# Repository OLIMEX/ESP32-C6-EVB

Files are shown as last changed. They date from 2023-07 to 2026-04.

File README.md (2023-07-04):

# ESP32-C6-EVB
ESP32-C6-EVB is evaluation board with WiFi6, Bluetooth 5LE and Zigbee Matter support

Product page: https://www.olimex.com/Products/IoT/ESP32-C6/ESP32-C6-EVB/open-source-hardware
## License
* Hardware is released under CERN OHL v1.2 license
* Software is released under GPL3 License
* Documentation is released under CC BY-SA 3.0

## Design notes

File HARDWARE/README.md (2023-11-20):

# ESP32-C6-EVB

Design files for Olimex ESP32-C6-EVB. Board is made with KiCAD. This is an open-source hardware project, released under CERN OHL v1.2 license.

STL files for a 3d printed case can be found in directory "3D printed case". All STL files were created with Fusion 360.

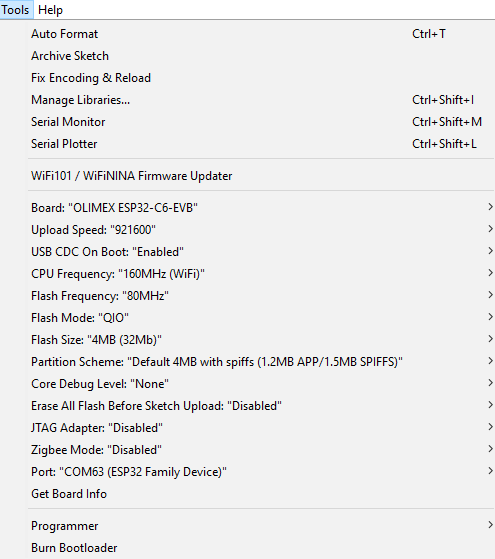
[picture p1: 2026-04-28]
SOFTWARE/ARDUINO/esp32-c6-serial-control/arduino-settings.jpg

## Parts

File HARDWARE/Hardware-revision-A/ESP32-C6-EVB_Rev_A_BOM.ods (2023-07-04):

Qty | Designation | Package | Designator
1 | 0.03R/1%/R1206 | R_1206_5MIL_DWS | R4
1 | 4.7R/R0402 | R_0402_5MIL_DWS | R12
1 | 100R/R0402 | R_0402_5MIL_DWS | R32
8 | 2.2k/R0402 | R_0402_5MIL_DWS | R3,R11,R15,R27,R28,R29,R30,R31
4 | 3.9k/R1206 | R_1206_5MIL_DWS | R5,R6,R7,R8
2 | 5.1k/R0603 | R_0603_5MIL_DWS | R1,R2
1 | 5.23k/1%/R0402 | R_0402_5MIL_DWS | R13
4 | 10k/R0402 | R_0402_5MIL_DWS | R14,R16,R25,R26
1 | 30.1k/1%/R0402 | R_0402_5MIL_DWS | R17
4 | 47k/R0402 | R_0402_5MIL_DWS | R21,R22,R23,R24
1 | 49.9k/1%/R0402 | R_0402_5MIL_DWS | R20
1 | 220k/R0402 | R_0402_5MIL_DWS | R19
1 | 12pF/50V/5%/COG/C0402 | C_0402_5MIL_DWS | C5
2 | 100nF/100V/10%/X7R/C0603 | C_0603_5MIL_DWS | C2,C4
1 | 100nF/10V/10%/X7R/C0402 | C_0402_5MIL_DWS | C10
1 | 1uF/10V/10%/X5R/C0603 | C_0603_5MIL_DWS | C11
4 | 22uF/6.3V/20%/X5R/C0603 | C_0603_5MIL_DWS | C3,C7,C8,C9
1 | 100uF/63V/20%/10x13MM/Low_ESR/RM5 | CPOL-RM5mm_10.0x16.0mm_PTH | C1
1 | 470uF/10V/20%/Low_ESR/RM2.5/6x11mm | CPOL-RM2.5mm_6.3x11mm_PTH | C6
1 | 2.2uH/NRS3015T2R2MNGH/1.5A/ DCR=72mR/20%/3.00x3.00x1.50mm | CD32 | L2
1 | 33uH/2A/DCR=0.1R/20%/ DBS135(PD3316MT330) | DBS135 | L1
1 | SMAJ58A/SMA | SMA-KA | D1
8 | 1N4148W(SOD-123) | SOD-123_1C-2A_KA | D2,D3,D4,D5,D8,D9,D10,D11
1 | SS310/SMA | SMA-KA | D6
1 | 1N5822/SS34/SMA | SMA-KA | D7
5 | LED/RED/0603 | LED_0603_KA | LED1,LED2,LED3,LED4,PWR_LED1
5 | LED/GREEN/0603 | LED_0603_KA | LED5,LED6,LED7,LED8,USER_LED1
4 | LMUN2235LT1G(SOT-23) | SOT23 | T1,T2,T3,T4
1 | WPM2015-3/TR | SOT23 | FET1
4 | PC817CS_CYPC817(C-TP2) | H11A817C_SMD(PC817X3NIP06)_FP | OPT1,OPT2,OPT3,OPT4
1 | ESP32-C6-WROOM-1-N4 | ESP32-C6-WROOM-1-xx-UNI_MODULE | U3
1 | TX4138(ESOIC-8) | ESOIC-8 | U1
1 | SY8089AAAC(SOT23-5) | SOT-23-5 | U2
4 | RAS-0515 | Relay_RAS-05-15 | REL1,REL2,REL3,REL4
1 | USB-C-16P-F(A40-00119-A52-12) | USB2.0_TYPE-C(A40-00119-A52-12) | USB-OTG1
1 | P-B-V-10-LF | GBH-254-SMT-10 | UEXT1
4 | DG306-5.0-3P | TB3-DG306-5.0_3P | CON1,CON2,CON3,CON4
4 | DG306-5.0-2P | TB2-DG306-5.0_2P | IN1,IN2,IN3,IN4
1 | NA(DG306-5.0-2P) | TB2-DG306-5.0_2P | PWR2
1 | PWRJ-2mm(YDJ-1134) | PWRJ-2mm(YDJ-1136) | PWR1
1 | SM10B-SRSS-TB | SM10B-SRSS-TB | UEXT2
2 | YTS-A016-X | YTS-A016-X | BUT1,RST1
1 | Opened | SJ_1_SMALLER | 3.3V_E1
1 | NA(WU06S) | WU06S | ESP-PROG1
1 | NA(HN1x10) | HN1x10 | EXT1
3 | NA/R0402 | R_0402_5MIL_DWS | R9,R10,R18
2 | NA(2.2k/R0402) | R_0402_5MIL_DWS | R33,R34

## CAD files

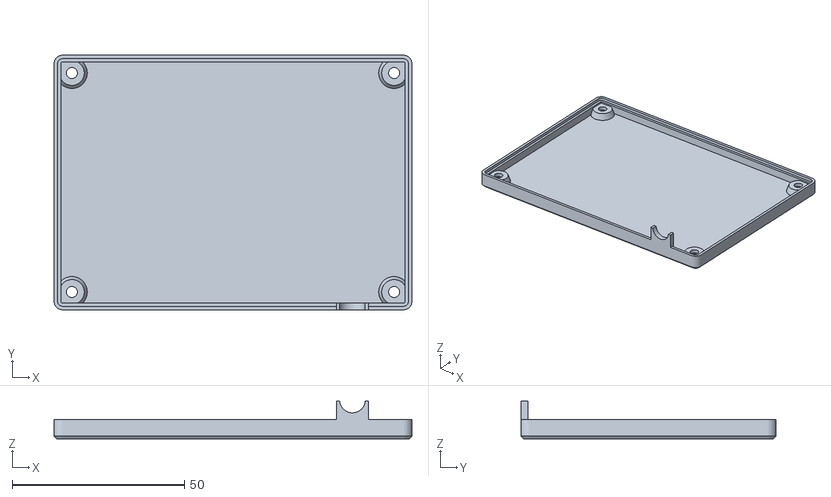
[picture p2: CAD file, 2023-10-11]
HARDWARE/3D printed case/esp_c6_evb_bottom.stl
104.0 x 74.0 x 11.0

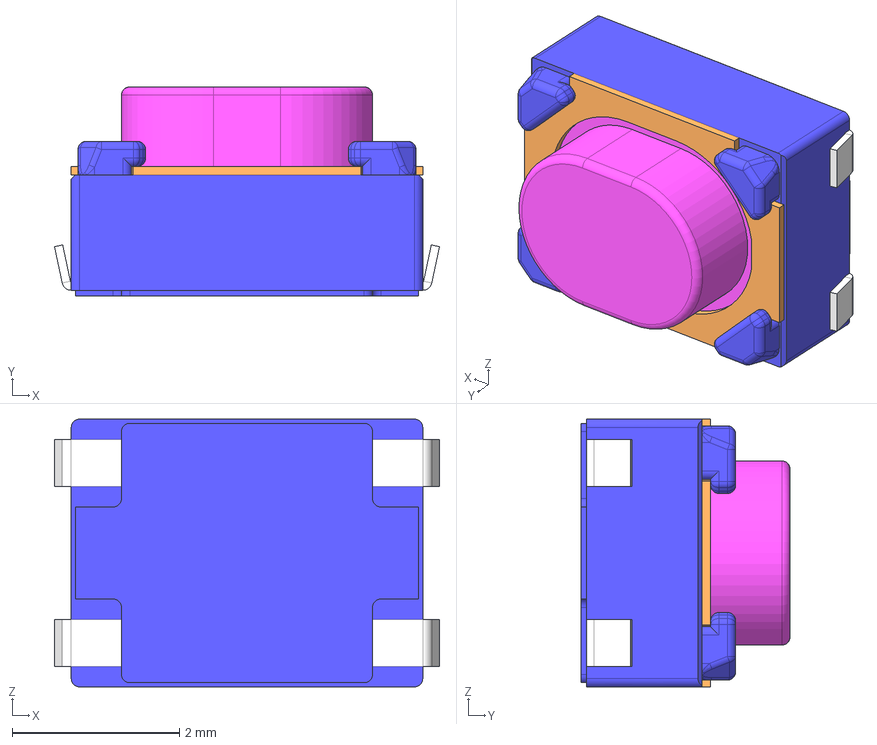
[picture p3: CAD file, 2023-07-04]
HARDWARE/Hardware-revision-A/3d/YTS-A016-X(SKRPABE010).stp
4.60 x 2.50 x 3.20 mm

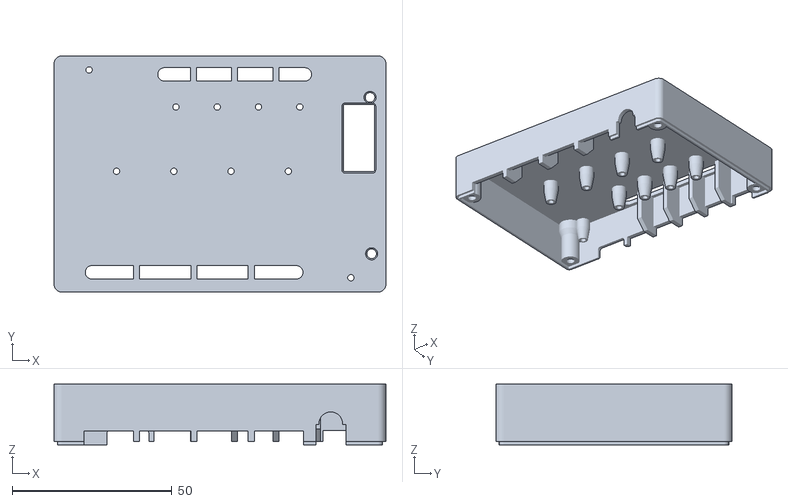
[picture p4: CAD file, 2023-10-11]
HARDWARE/3D printed case/esp_c6_evb_top.stl
104.0 x 74.0 x 19.0

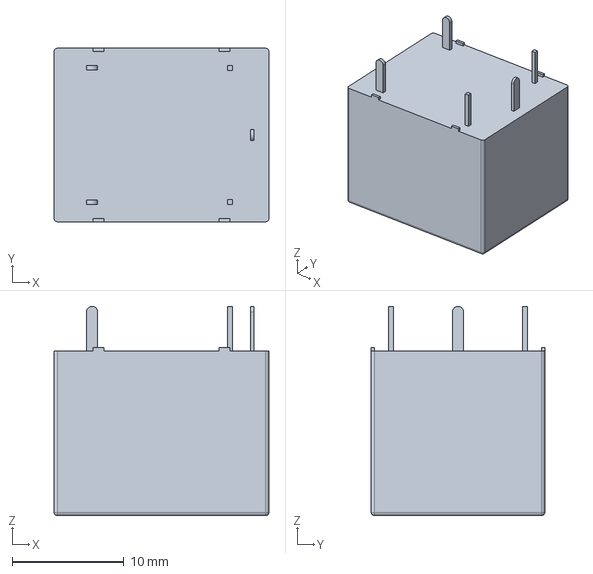
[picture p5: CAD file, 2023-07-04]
HARDWARE/Hardware-revision-A/3d/TEConnectivity -ORWH-SH-124D1F000.stp
19.2 x 15.5 x 18.7 mm

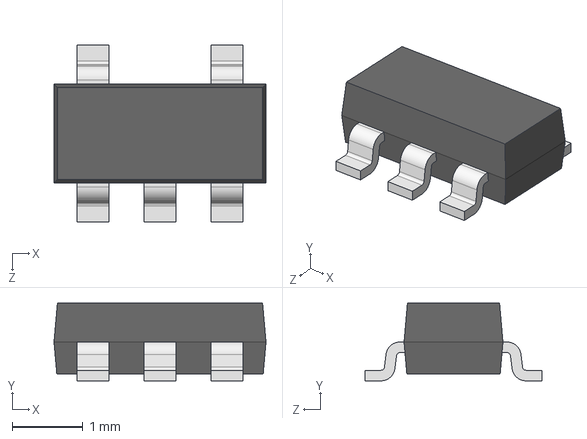
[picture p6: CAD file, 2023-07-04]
HARDWARE/Hardware-revision-A/3d/SOT-23-5.step
3.00 x 1.10 x 2.50 mm

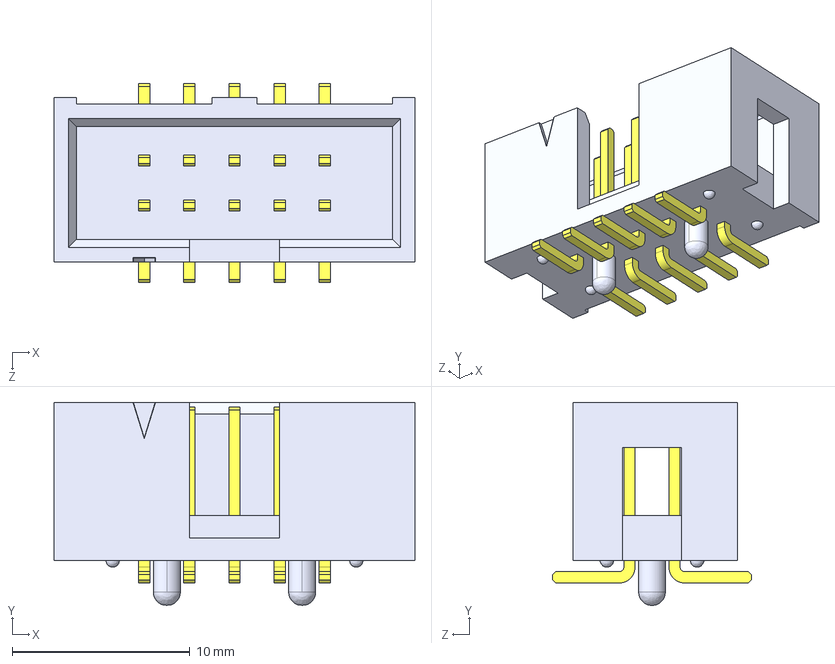
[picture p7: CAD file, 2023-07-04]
HARDWARE/Hardware-revision-A/3d/UEXT-SMD.STEP
20.3 x 11.4 x 11.2 mm
User Library-HTST-105-01-F-DV-A__HTST-105-01-DV-A_header
User Library-HTST-105-01-F-DV-A__HTST-First_Position_Indicator
User Library-HTST-105-01-F-DV-A__T-1S6-05-01-DV_

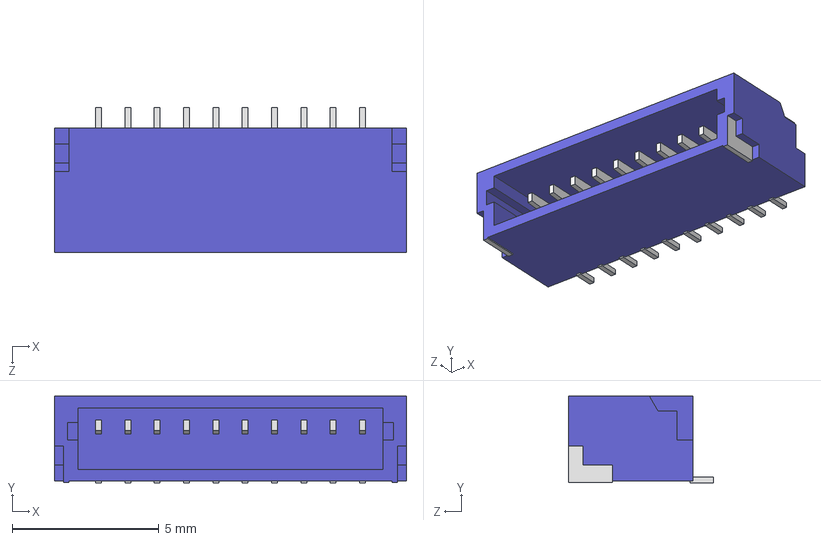
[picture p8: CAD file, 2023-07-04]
HARDWARE/Hardware-revision-A/3d/SM10B-SRSS-TB.STEP
12.0 x 2.96 x 4.95 mm

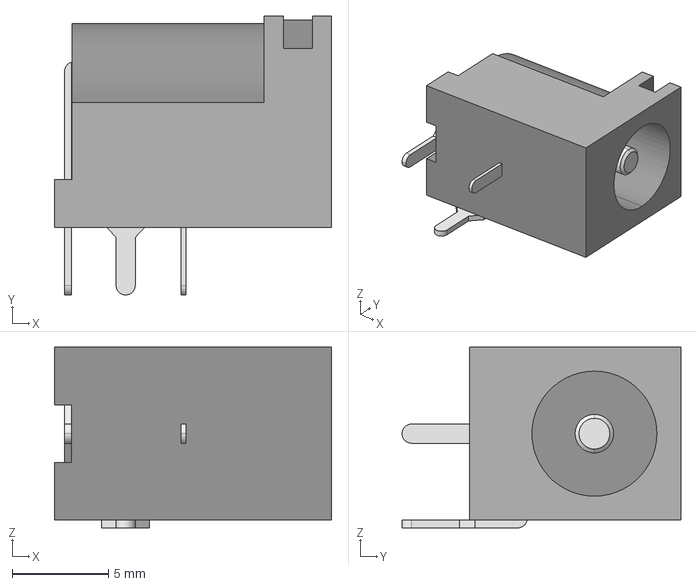
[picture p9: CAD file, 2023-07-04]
HARDWARE/Hardware-revision-A/3d/pj-102ah.stp
14.4 x 14.5 x 9.40 mm

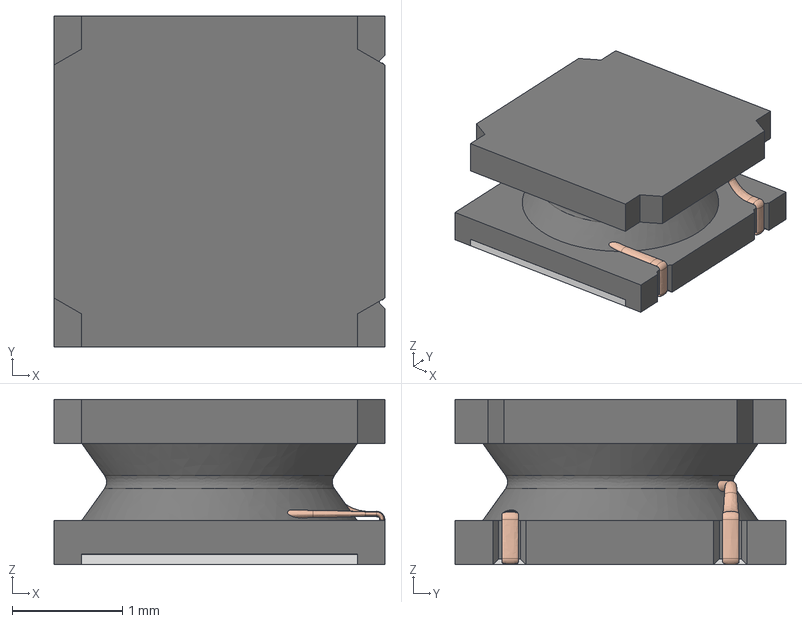
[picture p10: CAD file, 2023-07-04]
HARDWARE/Hardware-revision-A/3d/L-CD32_shielded.step
3.00 x 3.00 x 1.50 mm

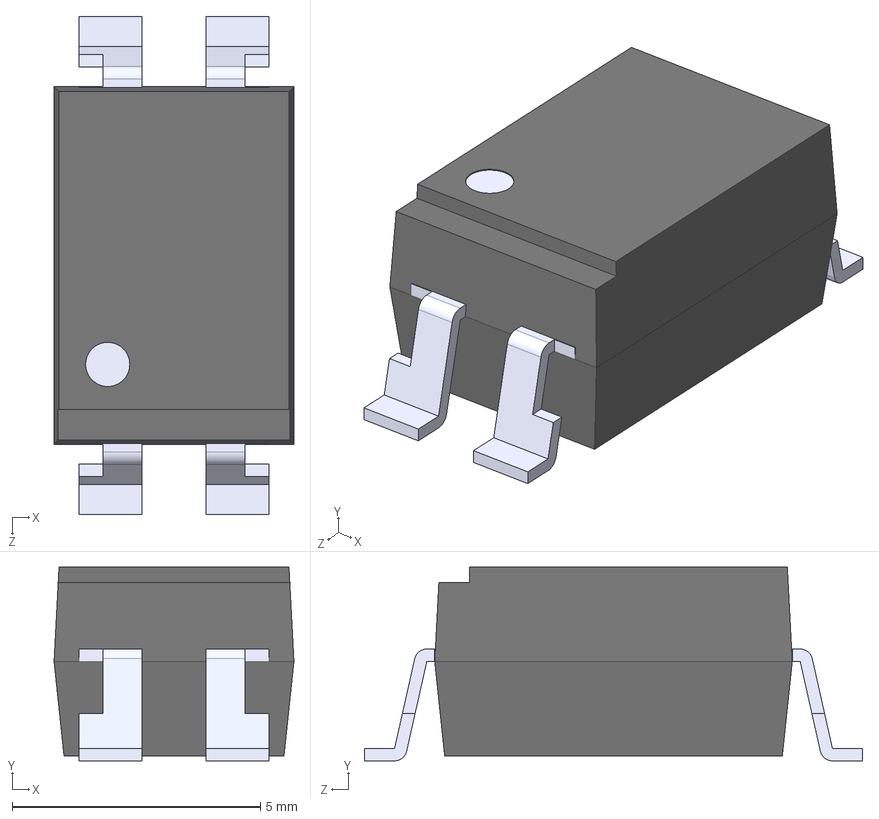
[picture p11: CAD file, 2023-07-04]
HARDWARE/Hardware-revision-A/3d/DIP4_opto_iso.step
4.83 x 3.90 x 10.0 mm

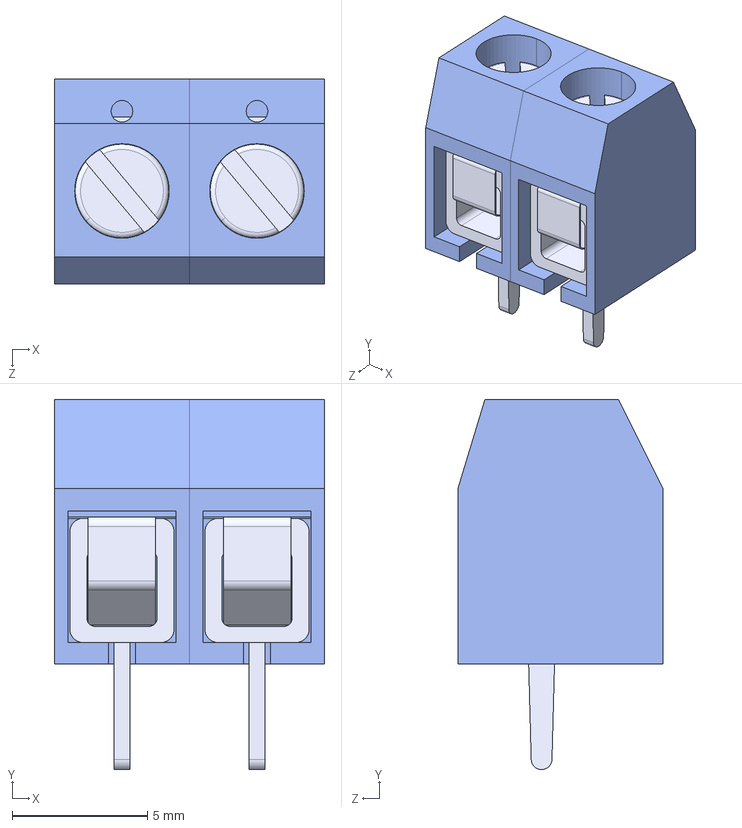
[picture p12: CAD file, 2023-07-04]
HARDWARE/Hardware-revision-A/3d/User Library-DG306-5_0-1.STEP
10.00 x 13.7 x 7.60 mm
Case___ _________ x 2
Leg___ _________ x 2
Spring___ _________ x 2
Cap___ _________ x 2

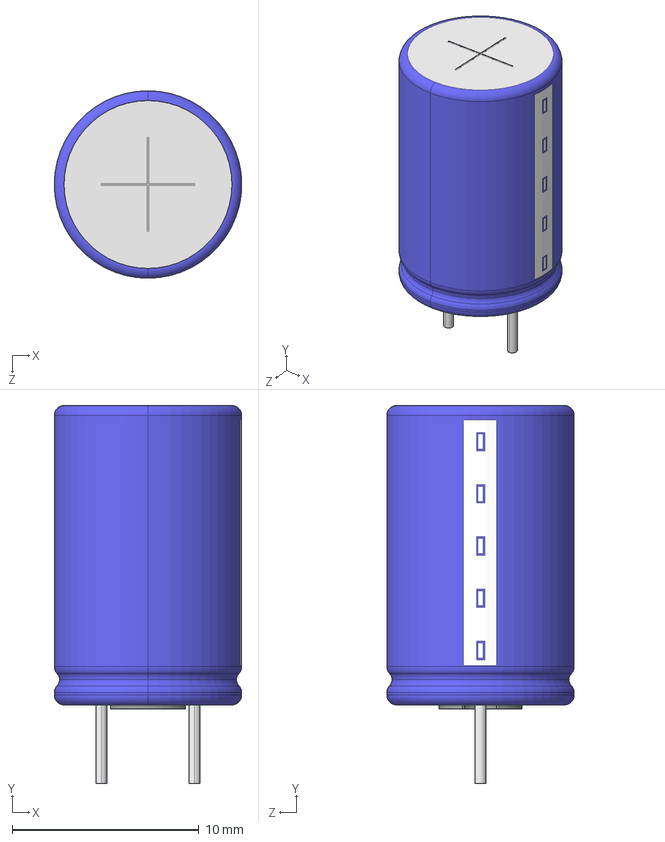
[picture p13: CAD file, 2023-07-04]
HARDWARE/Hardware-revision-A/3d/Cap_PTH_10x16x5_0mm.step
10.1 x 20.3 x 10.1 mm

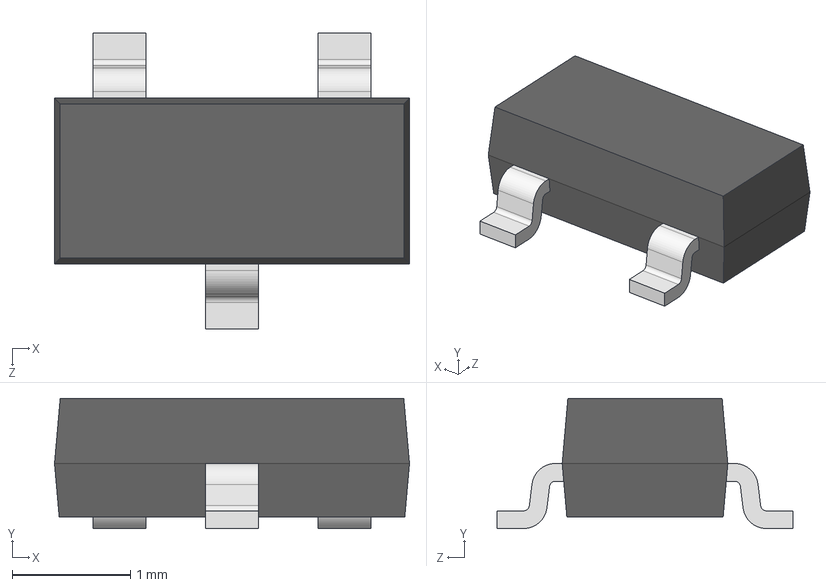
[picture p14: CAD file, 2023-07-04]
HARDWARE/Hardware-revision-A/3d/SOT-23.step
3.00 x 1.10 x 2.50 mm

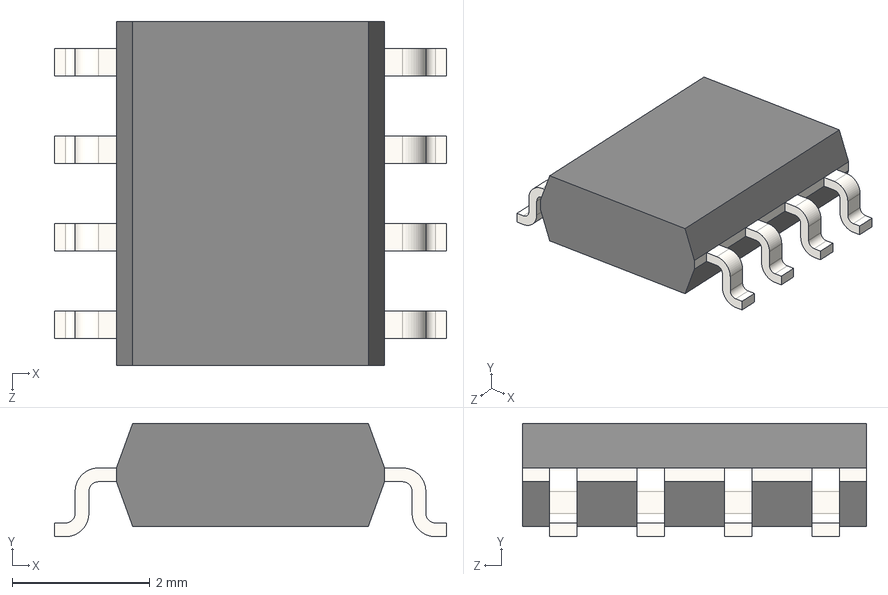
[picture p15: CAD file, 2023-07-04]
HARDWARE/Hardware-revision-A/3d/SL08.step
5.70 x 1.65 x 5.00 mm

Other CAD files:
HARDWARE/Hardware-revision-A/3d/Cap_PTH_6_3x11x2_5mm.step
HARDWARE/Hardware-revision-A/3d/klema-5mm-3pin.step
HARDWARE/Hardware-revision-A/3d/ESP32-WROOM-32D-56544.STEP
HARDWARE/Hardware-revision-A/3d/DO-214AC_SMA.step
HARDWARE/Hardware-revision-A/3d/L_AX97-103R3.step
HARDWARE/Hardware-revision-A/3d/SOD123.step

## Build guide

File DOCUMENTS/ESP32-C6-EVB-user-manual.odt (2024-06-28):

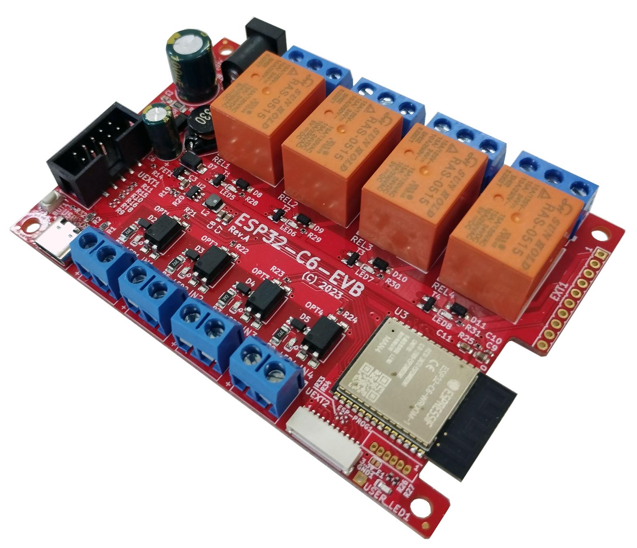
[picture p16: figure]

ESP32-C6-EVB

User Manual

Revision 2.0 June 2024 www.olimex.com

# INTRODUCTION

## What is ESP32-C6-EVB?

ESP32-C6-EVB (https://www.olimex.com/Products/IoT/ESP32-C6/ESP32-C6-EVB/open-source-hardware) is a WIFI-enabled and Bluetooth-enabled development board that also has free GPIOs, analog, and digital inputs and outputs on boxed connector and more.

ESP32-C6-EVB (https://www.olimex.com/Products/IoT/ESP32-C6/ESP32-C6-EVB/open-source-hardware) uses ESP32-C6, Espressif’s first Wi-Fi 6 (IEEE 802.11ax) module. It integrates 2.4 GHz Wi-Fi 6, Bluetooth 5 (LE), and the 802.15.4 low-rate wireless personal area network (LR-WPAN).

ESP32-C6-EVB (https://www.olimex.com/Products/IoT/ESP32-C6/ESP32-C6-EVB/open-source-hardware) is perfect for stand-alone usage but can also be attached to any existing hardware project to augment it with with 2.4GHz Wi-Fi 6 and Bluetooth LE 5.3 capabilities.

ESP32-C6-EVB (https://www.olimex.com/Products/IoT/ESP32-C6/ESP32-C6-EVB/open-source-hardware) requires only a USB cable for programming and powering; the board is equipped with USB type C connector, the type of cable used for charging most mobile phones.

ESP32-C6-EVB (https://www.olimex.com/Products/IoT/ESP32-C6/ESP32-C6-EVB/open-source-hardware) is an Open Source Hardware project, all CAD source files are available at our GitHub repositories (https://github.com/OLIMEX/ESP32-C6-EVB/tree/main/HARDWARE). Files are released under CERN Open Hardware License Version 2 – strongly reciprocal and allows users to learn, study, edit, modify, manufacture, and sell same, or derivative products based on these designs. The only requirements is to open source their work under the same license.

The software environment for code development is free. There are a number of different software environments that can be used for the board.

Espressif chips and modules are very popular, with excellent chip documentation. The community around ESP chips is huge. This greatly eases both hardware and software development.

ESP32-C6-EVB (https://www.olimex.com/Products/IoT/ESP32-C6/ESP32-C6-EVB/open-source-hardware) is RoHS, REACH, CE, and UKCA compliant.

## ESP32-C6-EVB board features

ESP32-C6-EVB is Open Source Hardware design with the following features:

- ESP32-C6-WROOM-1-N4 module with 32-bit RISC-V single-core microprocessor, up to 160 MHz, Flash: 4MB, ROM: 320 KB, HP SRAM: 512 KB, LP SRAM: 16 KB
- USB-C connector for powering, programming, and JTAG debugging
- Power jack for optional external power (8-50)V DC
- Four Relays: 10A/240VAC
- Four opto-isolated inputs for DC voltage up to 30VDC
- Two UEXT connectors (0.1" step one and JST one)
- Extension GPIO connector
- Reset button
- User button
- Wide range of power supply: 8-50VDC
- Programming connector suitable for ESP-PROG (https://www.olimex.com/Products/IoT/Programmer/ESP-PROG/open-source-hardware)
- Four mount holes
- Four rubber pads included

## Order codes and links for ESP32-C6-EVB and accessories:

ESP32-C6-EVB (https://www.olimex.com/Products/IoT/ESP32-C6/ESP32-C6-EVB/open-source-hardware) ESP32-C6 development and evaluation board with 4 relays, 4 opto-isolated inputs, and more.

CABLE-USB-A-C-1M (https://www.olimex.com/Products/Components/Cables/CABLE-USB-A-C-1M/) USB cable with USB type C and USB type A connectors, 1 meter

SY0612E (https://www.olimex.com/Products/Power/SY0612E/) 12V DC power adapter for external powering, compatible with the power jack (https://www.olimex.com/wiki/PWRJACK) of ESP32-C6-EVB; notice that it comes with European-style socket plug, if you are located in UK or USB consider PWR-EU-EK (https://www.olimex.com/Products/Power/PWR-EU-UK/) or PWR-EU-US (https://www.olimex.com/Products/Power/PWR-EU-US/) adapter

ESP-PROG (https://www.olimex.com/Products/IoT/Programmer/ESP-PROG/open-source-hardware) External USB-serial adapter that can be attached to ESP32-C6-EVB and used to program the ESP32-C6, or restore its firmware

CABLE-IDC10-15cm (https://www.olimex.com/Products/Components/Cables/CABLE-IDC10-15cm/) 10-pin female-female UEXT cable

JW-200x10-FM (https://www.olimex.com/Products/Breadboarding/JUMPER-WIRES/JW-200x10-FM/) 10 pieces female-male jumper wires for breadboarding

JW-200x10 (https://www.olimex.com/Products/Breadboarding/JUMPER-WIRES/JW-200x10/) 10 pieces male-male jumper wires for breadboarding

JW-200x10-FF (https://www.olimex.com/Products/Breadboarding/JUMPER-WIRES/JW-200x10-FF/) 10 pieces female-female jumper wires for breadboarding

UEXT modules (https://www.olimex.com/Products/Modules/) Different sensors, relays, LCDs, RTC, GSM, GPS etc accessories which can be connected to the UEXT connector

## ESP32-C6 reference documents:

- ESP32-C6-WROOM-1U-N4 (the module used in ESP32-C6-EVB) datasheet:

https://www.espressif.com/sites/default/files/documentation/esp32-c6-wroom-1_wroom-1u_datasheet_en.pdf

- ESP32-C6 series (the chip in ESP32-C6-WROOM-1U-N4 and, respectively, in ESP32-C6-EVB) datasheet:

https://www.espressif.com/sites/default/files/documentation/esp32-c6_datasheet_en.pdf

- Getting started with ESP32-C6 and ESP-IDF software environment:

https://docs.espressif.com/projects/esp-idf/en/latest/esp32c6/get-started/

- Getting started with ESP32-C6 and ESP32 package for Arduino IDE and PlatformIO software environments:

https://docs.espressif.com/projects/arduino-esp32/en/latest/getting_started.html

# HARDWARE

## ESP32-C6-EVB layout

4 x Relays with connectors and status LEDs (10A/240VAC max)

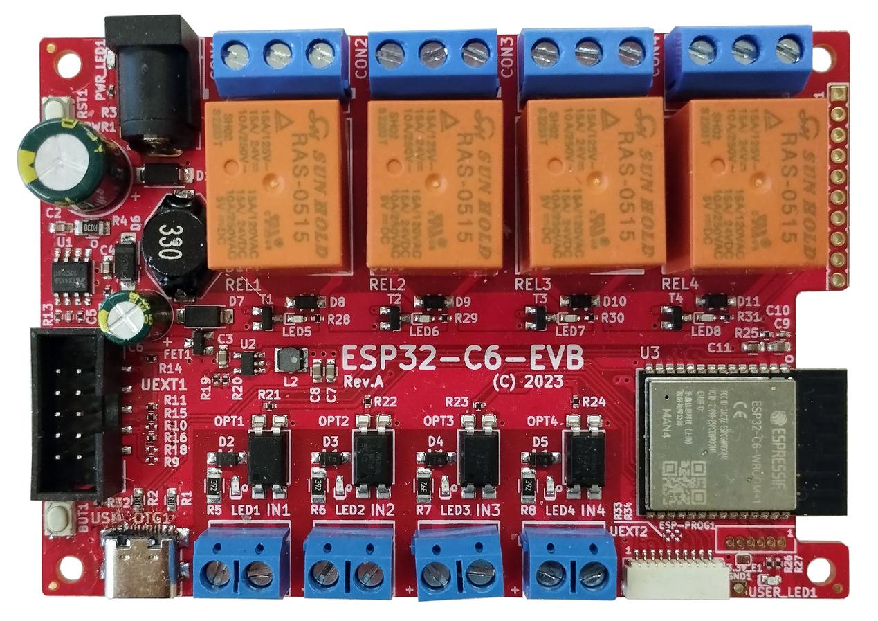
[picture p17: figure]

Power-good LED

Power jack input

(8-50)V DC

Reset button RST1

EXT1 header

4 x Opto-coupler inputs with connectors and status LEDs (30V DC max)

User LED

USB type C

for power and

programming

Boot/User button BUT1

UEXT1 connector 0.1” step

ESP-PROG1 header

UEXT2 connector (JST)

## ESP32-C6-EVB schematic

The latest ESP32-C6-EVB (https://www.olimex.com/Products/IoT/ESP32-C6/ESP32-C6-EVB/open-source-hardware) schematic is available on the next page.

You can also download PDF export from GitHu (https://github.com/OLIMEX/ESP32-C6-EVB/blob/main/HARDWARE/Hardware-revision-A/ESP32-C6-EVB_Rev_A.pdf)b here (https://github.com/OLIMEX/ESP32-C6-EVB/blob/main/HARDWARE/Hardware-revision-A/ESP32-C6-EVB_Rev_A.pdf)

All design sources are available also at GitHub (https://github.com/OLIMEX/ESP32-C6-EVB/tree/main/HARDWARE)here (https://github.com/OLIMEX/ESP32-C6-EVB/tree/main/HARDWARE)

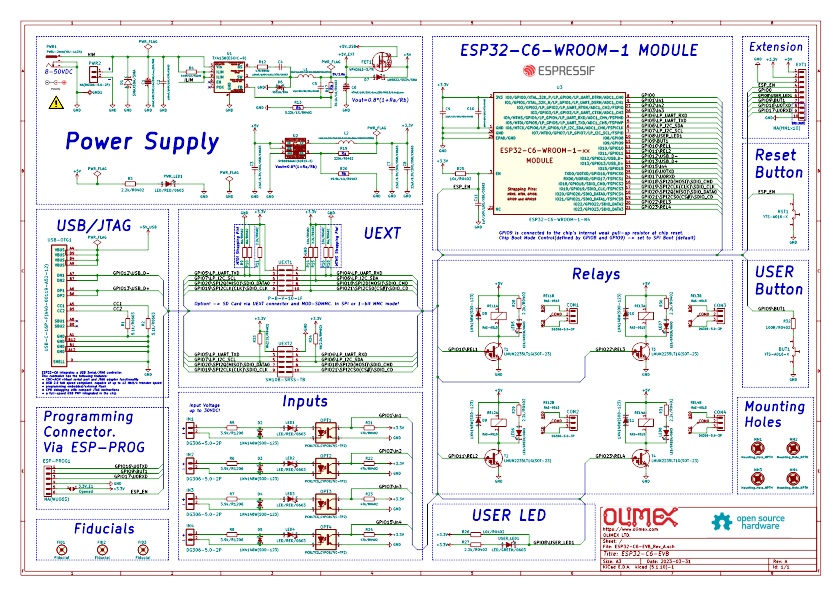
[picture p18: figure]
SVG Picture created as ESP32-C6-EVB_Rev_A.svg date 2023/08/03 15:58:47 Picture generated by Eeschema-SVG

## ESP32-C6-EVB power supply and consumption:

(https://www.olimex.com/Products/Retro-Computers/AgonLight2/open-source-hardware)

ESP32-C6-EVB can be powered by 3 sources:

- USB-C connector;
- Power jack connector;
- EXT1.pin1 (+5V) note that this wire is connected to the 5V of the USB so when you power ESP32-C6-EVB from EXT1.pin1 – you should not have USB cable attached at the same time!!!

The typical power consumption is under 1W. Current consumption of ESP32-C6-EVB is approximately 0.06A when powered by 12V DC (applied to the power jack).

## EXT1 connector (GPIO)

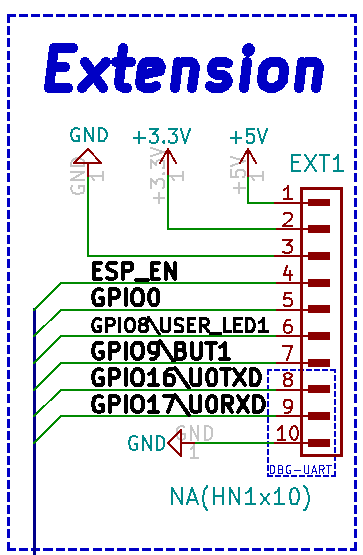
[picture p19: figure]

EXT1 pin #1 is +5V pin; it is usually used as output you can also power the board from this pins BUT ONLY IF the USB-C is not connected! It must be regulated 5V power supply, applying more than 5V will damage the board;

EXT1 pin #2 is +3.3V DC output, it is not recommended to be used as input since you can’t fully power the board with 3.3V DC (relays require 5V DC);

EXT1 pin #3, EXT1 pin #10 are GND pins, the board has common ground;

EXT1 pin #4 is ESP_EN also known as reset;

EXT1 pin #5 is GPIO0, which a free pin;

EXT1 pin #6 is GPIO8\USER_LED1 – wired to GPIO8, notice that the user LED is on the same wire

EXT1 pin #7 is GPIO9\BUT1 – wired to GPIO9, notice that the button is on the same wire

EXT1 pin #8 and EXT1 pin #9 are GPIO16\U0TXD and GPIO16\U0RXD they can be used for attaching external USB-serial converter (like ESP-PROG, USB-SERIAL-CABLE-M, or BB-CH340T) to debug the board; same pins are also routed to the ESP-PROG1 header.

All GPIOs operate at +3.3V levels. This means you should not connect signals with voltage higher than 3.3V to these ports as this will damage the board.

## UEXT connectors

UEXT connector stands for Universal EXTension connector and contains +3.3V output and GND power wires, and I2C, SPI, UART data signals. All signals are at 3.3V levels.

ESP32-C6-EVB has two UEXT connectors – UEXT1 and UEXT2, they have the same signals just different connector.

UEXT1 uses 0.1” 2.54mm step 2-row boxed plastic connector.

UEXT2 uses the smallest pUEXT which is 1.0mm single row JST connector.

Excerpts for UEXT1 and UEXT2 connectors can be seen below:

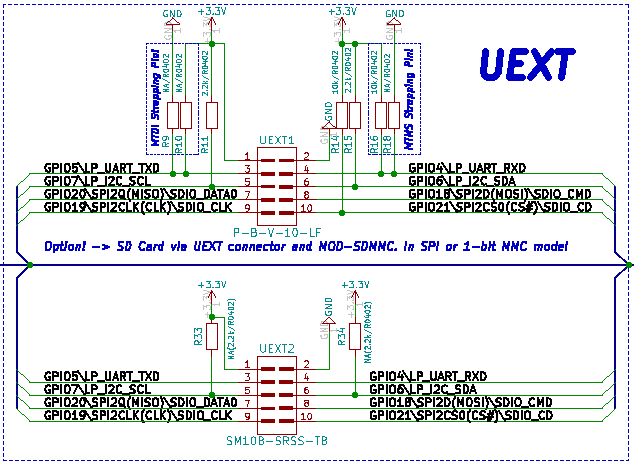
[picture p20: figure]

Olimex has developed number of extension MODULES (https://www.olimex.com/Products/Modules/) compatible with connector UEXT1. There are temperature, humidity, pressure, magnetic field, light sensors. Modules with LCDs, extra GPIOs, LED matrices, relays, Bluetooth, GSM, GPS, RFID, RTC, EKG, etc.

If you decide to use UEXT2 you might need adapter for the connector pUEXT. Expect adapter boards and wires for the JST UEXT2 connector.

## Relays

The board has 4 electro-mechanical relays for analog output, each relay has own status LED. Relay connectors have Normal open, Normal closed, and Common contacts.

Relay REL1 is connected to GPIO10

Relay REL2 to GPIO11

Relay REL3 goes to GPIO22

Relay REL4 to GPIO23

## Inputs

The board has 4 optocouplers for analog input and each input has own status LED. The inputs have + and – printed under the connector – make sure to first check the polarity or you might damage the board.

Opto OPT1 is connected to GPIO1

Opto OPT2 goes to GPIO2

Opto OPT3 is routed to GPIO3

Opto OPT4 is connected to GPIO15

## User LED and button BUT1

The board has user LED and a button that can be used as boot button but also can be used as user button after initial boot sequence.

LED is connected to GPIO8

Button BUT1 is connected to GPIO9

## ESP32-PROG header

Used to program the board with external serial-USB programmer like (like ESP-PROG (https://www.olimex.com/Products/IoT/Programmer/ESP-PROG/open-source-hardware))

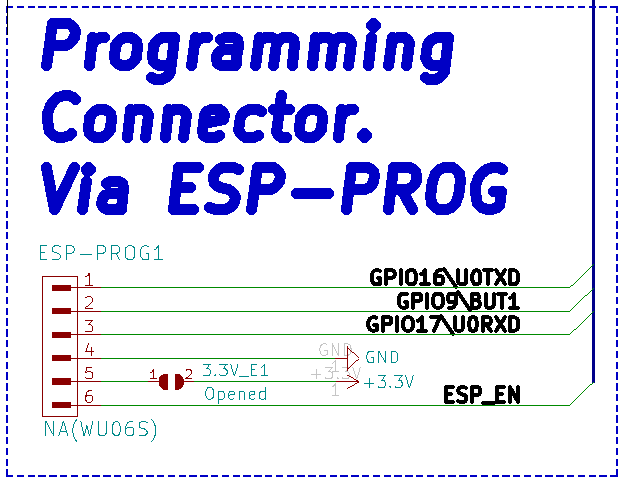
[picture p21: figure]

## Jumper 3.3V_E1

ESP32-C6-EVB has a single SMT jumpers on-board. SMT jumpers are pads that can be separated (open) or soldered together (closed) to alter the hardware connections of the board and alter the behavior. The SMT jumpers require basic soldering tools and experience, to separate them you need to cut between the pads and to close them you need to solder the pads together. SMT jumpers can also be used for measuring and testing purposes.

Typically you don’t need to change the positions of the jumpers to use the board. It is not recommended to alter the SMT jumpers unless you know exactly how they alter the board.

3.3V_E1 – enable 3.3V input on pin #5 of ESP-PROG1 connector – risky to leave 3.3V on the ESP-PROG1 connector, this might lead to short-circuit, if the board is already powered and you attach ESP-PROG (https://www.olimex.com/Products/IoT/Programmer/ESP-PROG/open-source-hardware).

Default state: Open (no 3.3V on pin #5 of ESP-PROG1 connector).

# SOFTWARE

## First time start up or how to program the board

The first time setup is pretty straight-forward and the general approach is the following:

1) Install compatible software on your computer (your computer should meet the requirements of the software); the official and recommended software is ESP-IDF (https://docs.espressif.com/projects/esp-idf/en/latest/esp32c6/get-started/); but you can also use ESP32 package for Arduino IDE (https://docs.espressif.com/projects/arduino-esp32/en/latest/getting_started.html)

2) Attach the ESP32-C6-EVB to the computer via USB cable, the cable needs to have USB type C connector at one end and usually USB type A at the other to fit your computer; a lot of devices use similar cables so you might already have such cable at home;

3) Force the board in upload/bootloader mode manually:

- Press and hold button BUT1

- Press and release button RST1

- Release button BUT1;

4) Download code. If you are unhappy with the default demos. Maybe check our ESP-IDF demo software for the relays, user LED, button – Olimex ESP32-C6-EVB demo code (https://github.com/OLIMEX/ESP32-C6-EVB/tree/main/SOFTWARE/ESP-IDF) and there is some extra info about it here (https://github.com/OLIMEX/ESP32-C6-EVB/blob/main/SOFTWARE/ESP-IDF/ESP32-C6-EVB_Blink/ESP32-C6-EVB_README.txt)in this text file (https://github.com/OLIMEX/ESP32-C6-EVB/blob/main/SOFTWARE/ESP-IDF/ESP32-C6-EVB_Blink/ESP32-C6-EVB_README.txt);

5) After download is complete you might need to reboot the board to have the user code execute. Future downloads would require entering upload/bootloader mode again (refer to 3).

## Olimex tested firmware and examples

These can be found in the repository here:

https://github.com/OLIMEX/ESP32-C6-EVB

# DOCUMENT REVISION

Revision 2.0 June 2024

- minor improvements

- added links to ESP32 package for Arduino

Revision 1.0 August 2023

- initial release

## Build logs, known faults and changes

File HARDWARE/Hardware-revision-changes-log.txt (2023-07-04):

Notable hardware changes for ESP32-C6-EVB

Notice that the board is designed with KiCAD

---

Hardware revision A:

- initial release

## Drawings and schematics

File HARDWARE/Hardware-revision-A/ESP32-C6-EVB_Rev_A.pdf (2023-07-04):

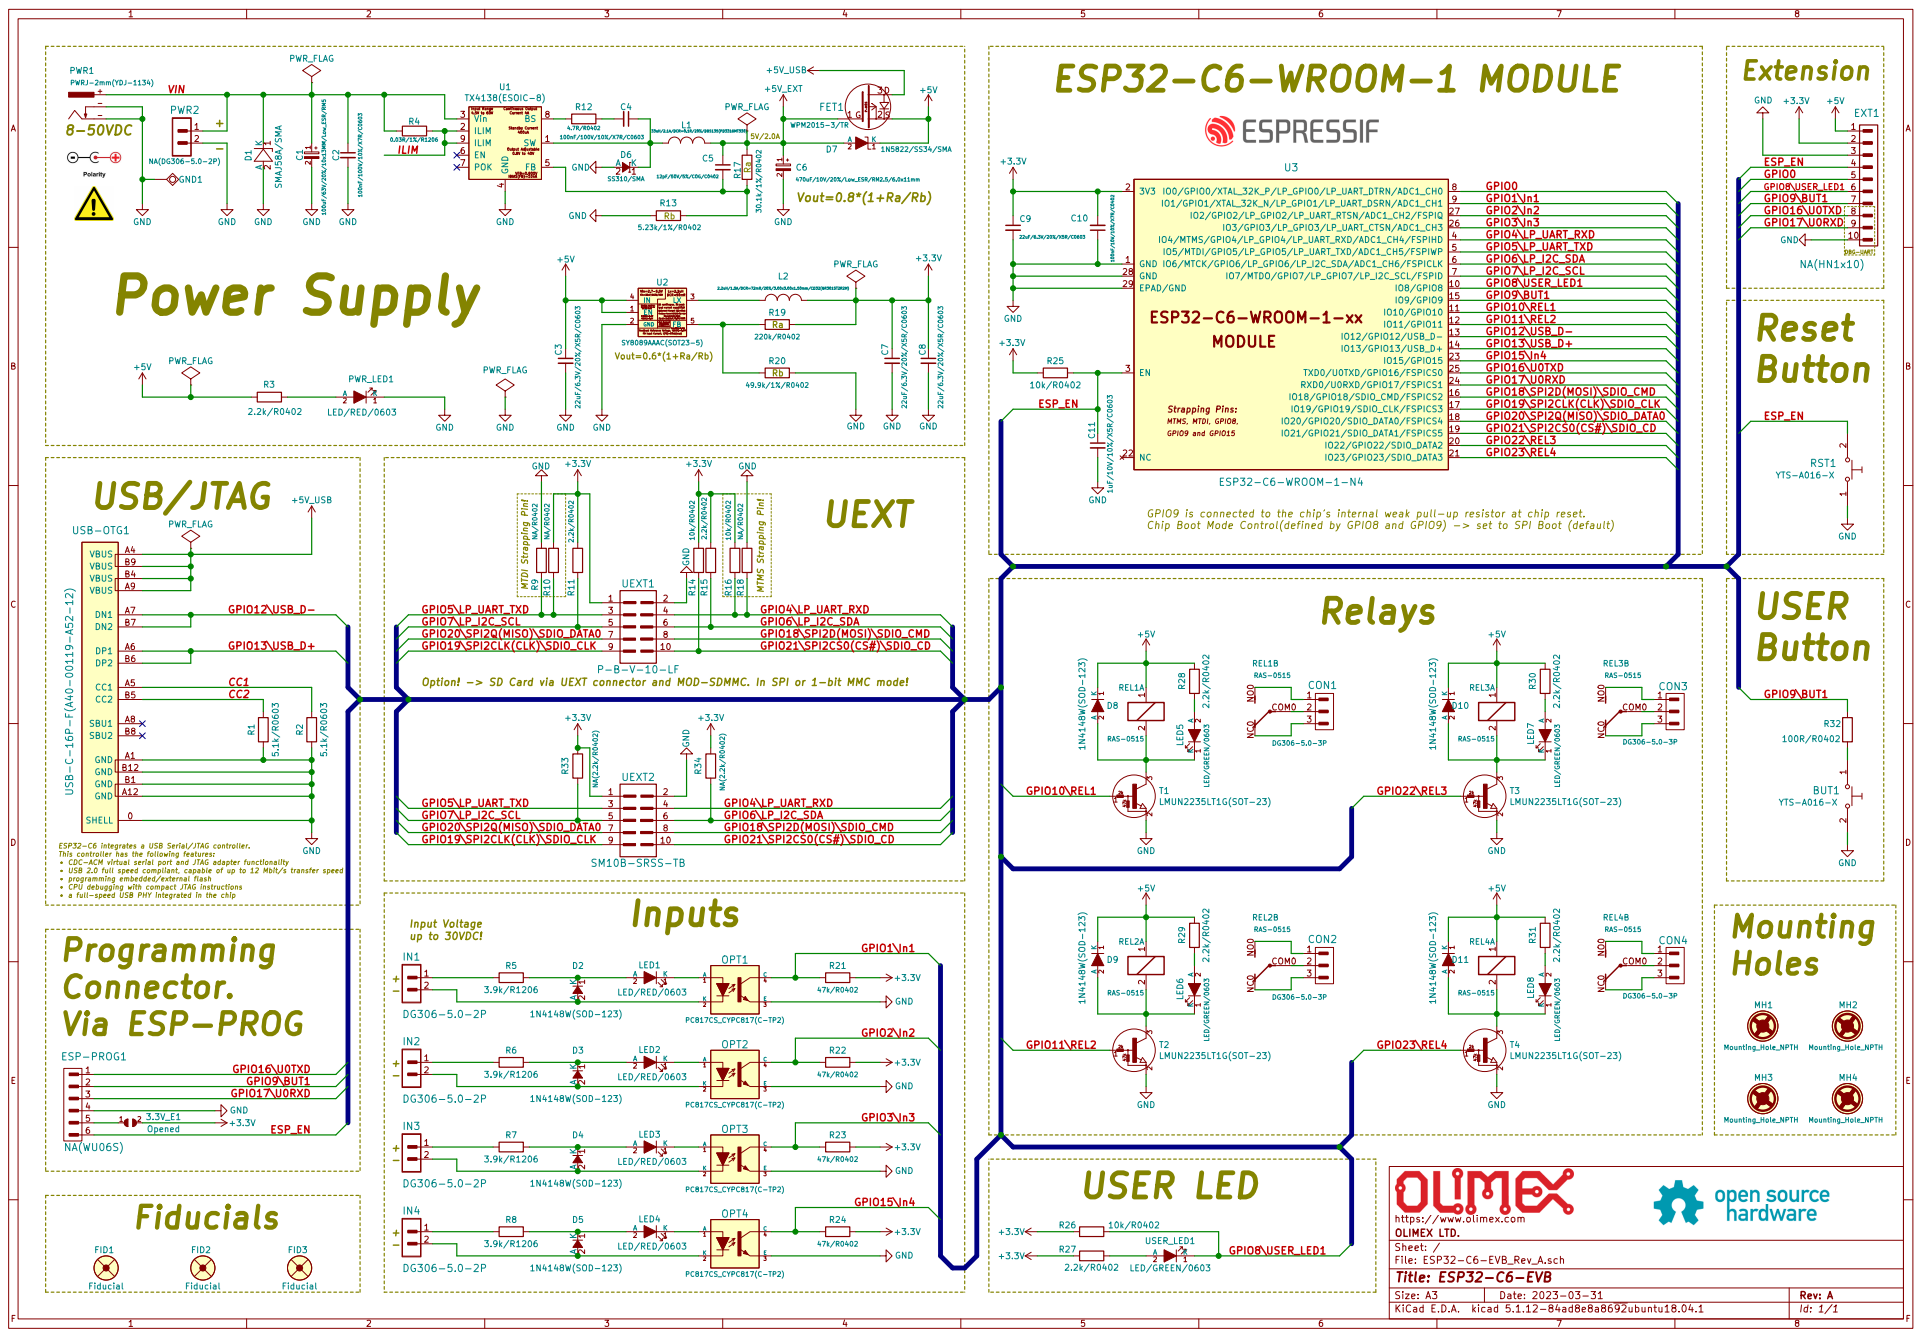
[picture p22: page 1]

4 FB 5 EN 6 POK 7 BS 8

2 D1 SMAJ58A/SMA GND GND GND

MTMS, MTDI, GPIO8, Strapping Pins: GND 1

load current capability! Lx=2.2uH

Do not float. Enable control. FB Input Current, I(FB)=50nA(max) Feedback Reference Voltage, V(REF)=0.6V

GPIO9 is connected to the chips internal weak pull-up resistor at chip reset. Chip Boot Mode Control(defined by GPIO8 and GPIO9) -> set to SPI Boot (default) ESP32-C6 integrates a USB Serial/JTAG controller. This controller has the following features:

CDC-ACM virtual serial port and JTAG adapter functionality
USB 2.0 full speed compliant, capable of up to 12 Mbit/s transfer speed
programming embedded/external flash
CPU debugging with compact JTAG instructions
+ Programming
Connector.

- Mounting
Input Voltage up to 30VDC!
RAS-0515 1

File: ESP32-C6-EVB_Rev_A.sch Sheet: / OLIMEX LTD. https://www.olimex.com

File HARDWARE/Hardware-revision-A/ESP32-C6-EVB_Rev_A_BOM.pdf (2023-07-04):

ESP32-C6-EVB_Rev_A_BOM | 03/31/2023

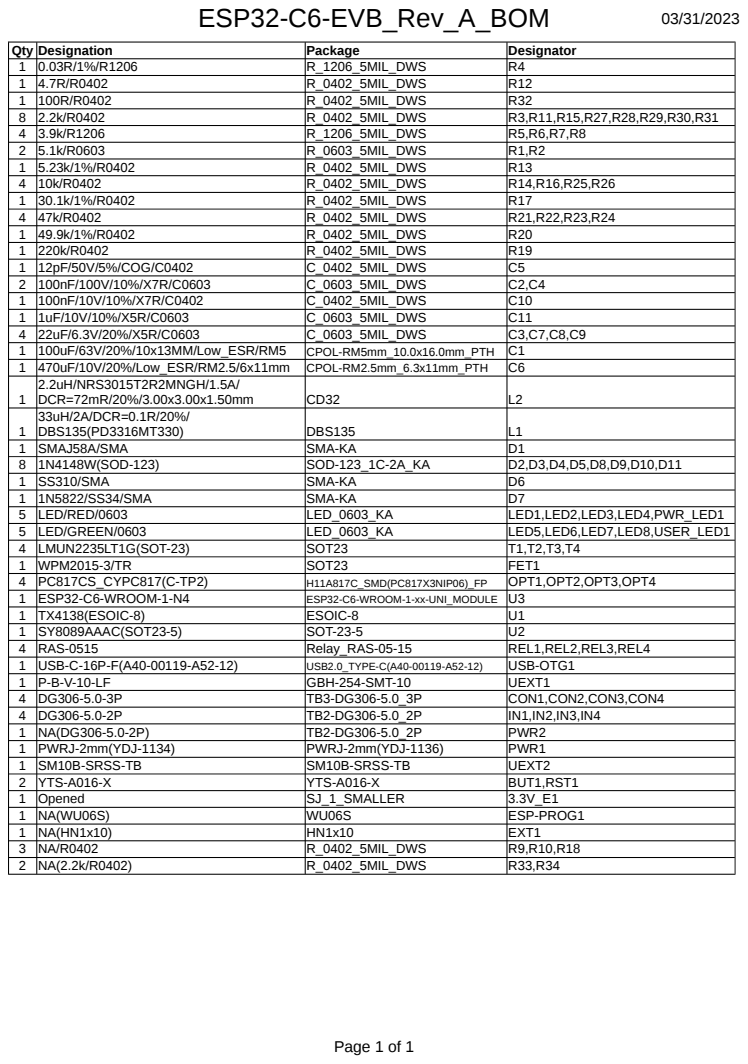
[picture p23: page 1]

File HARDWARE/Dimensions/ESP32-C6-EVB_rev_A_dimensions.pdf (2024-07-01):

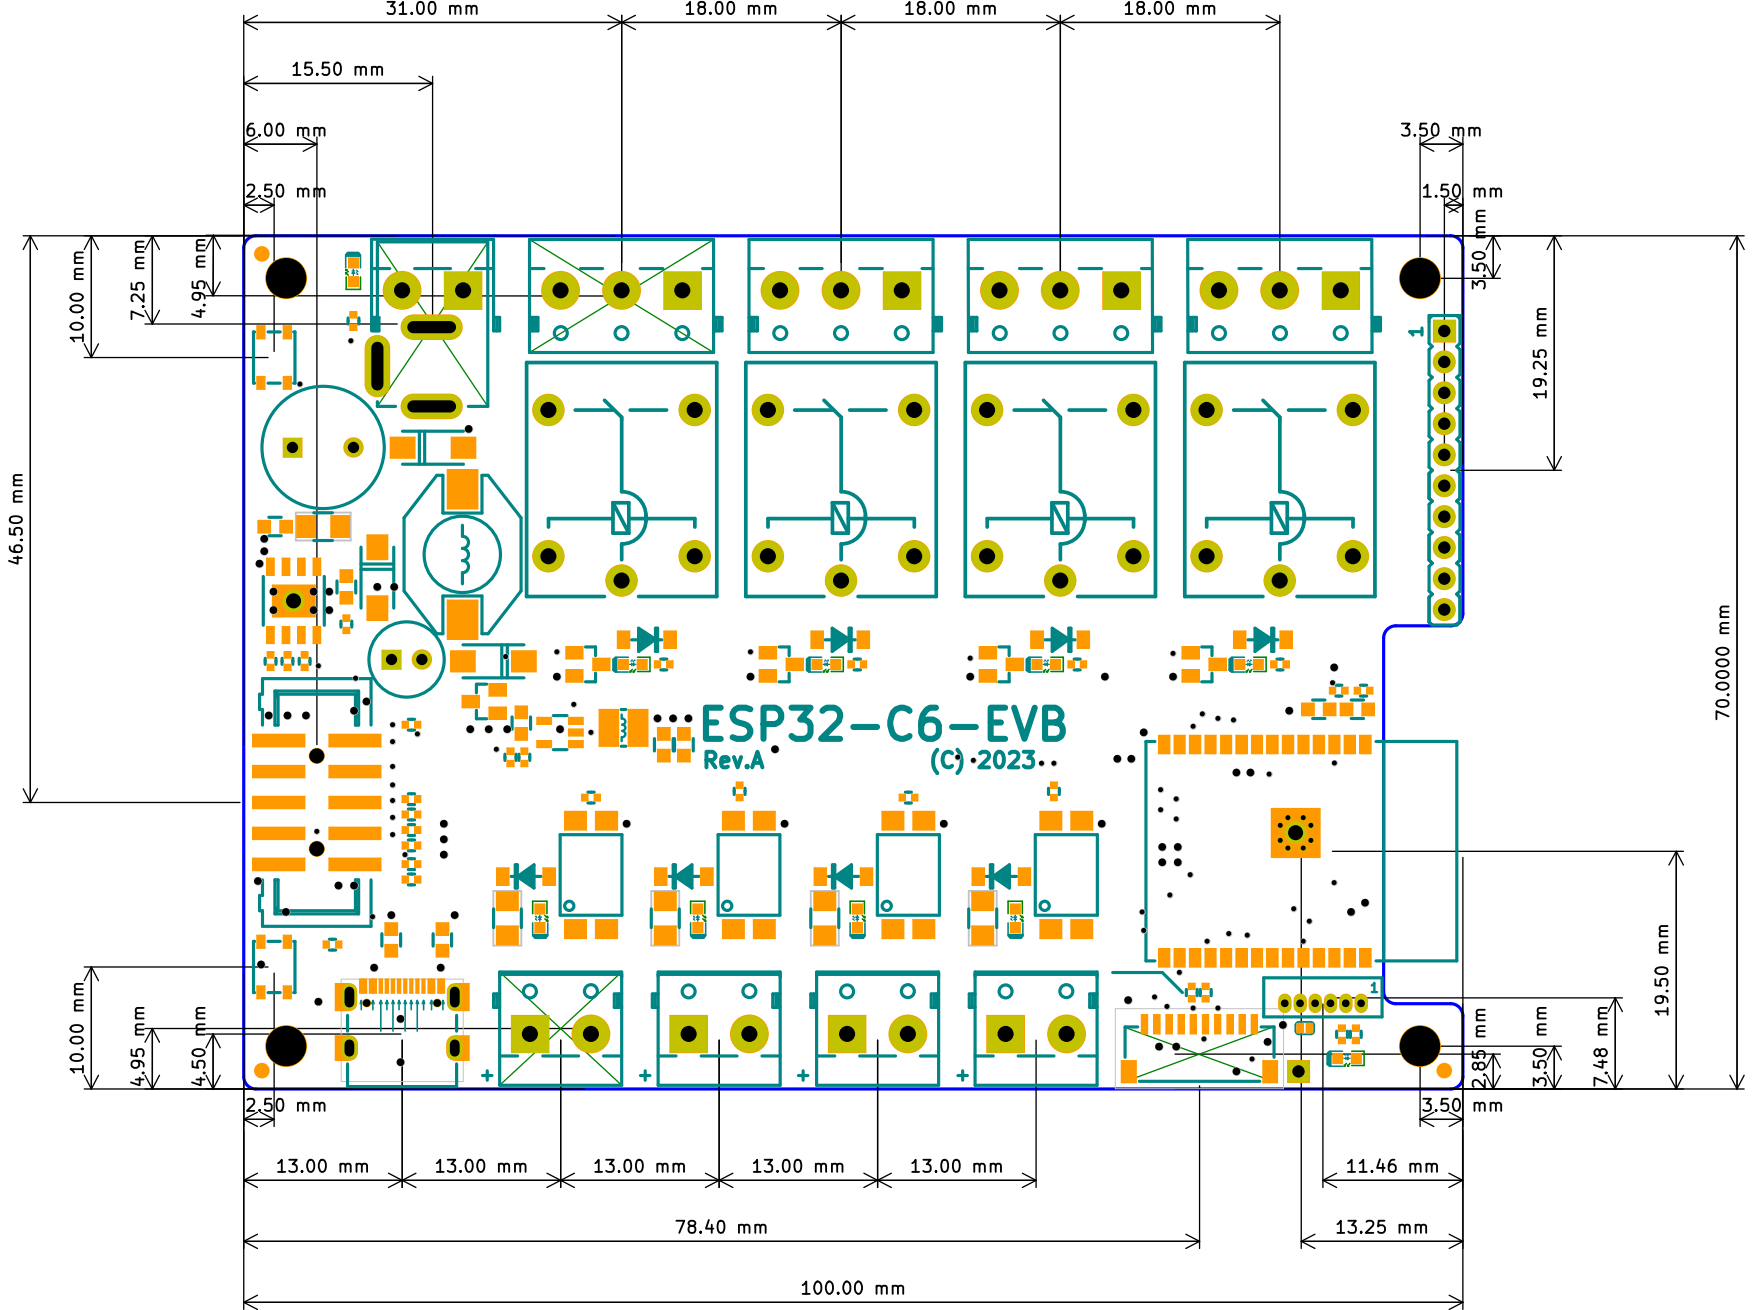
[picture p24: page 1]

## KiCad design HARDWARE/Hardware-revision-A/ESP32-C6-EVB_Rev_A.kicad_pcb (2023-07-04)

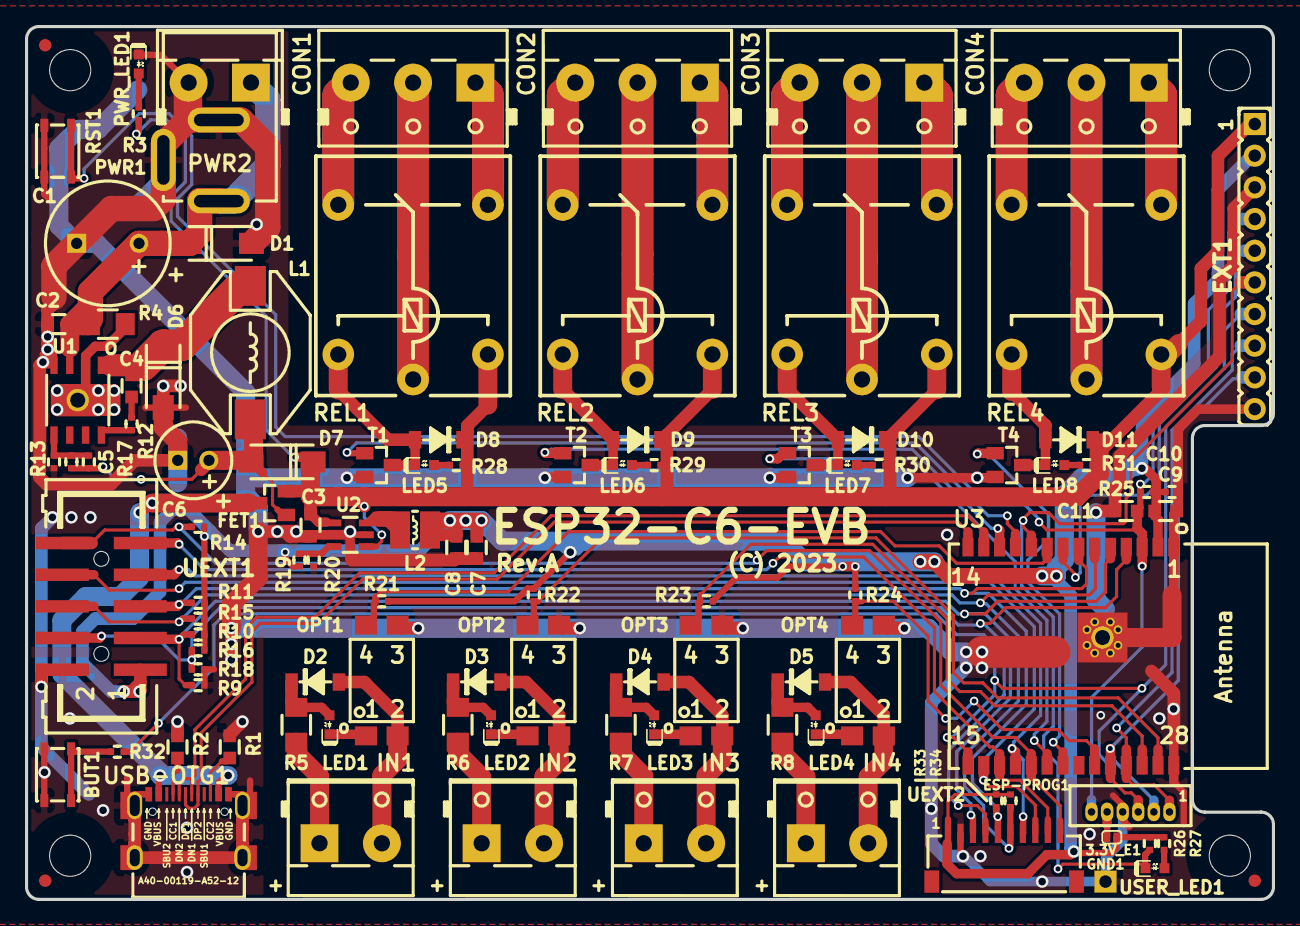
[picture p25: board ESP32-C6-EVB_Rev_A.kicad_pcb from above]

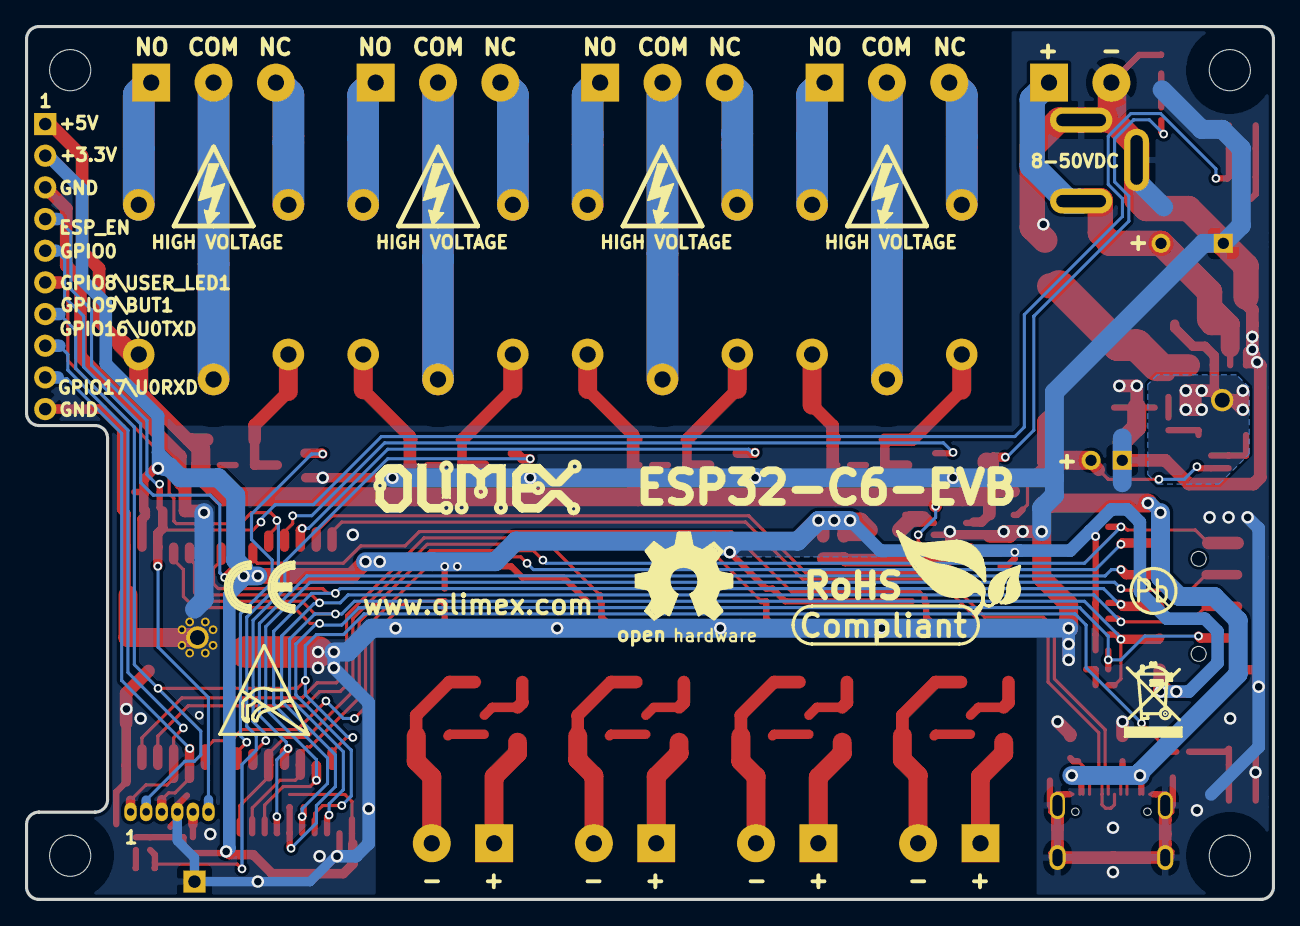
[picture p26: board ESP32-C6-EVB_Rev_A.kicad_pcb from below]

Board: 2 copper layers, 100.0 x 70.0 mm, 121 parts (11 on the bottom side), 79 nets.

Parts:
3.3V_E1: Opened; SJ_1_SMALLER
BUT1: YTS-A016-X
C1: 100uF/63V/20%/10x13MM/Low_ESR/RM5; CPOL-RM5mm_10.0x16.0mm_PTH
C2, C4: 100nF/100V/10%/X7R/C0603; C_0603_5MIL_DWS
C3, C7, C8, C9: 22uF/6.3V/20%/X5R/C0603; C_0603_5MIL_DWS
C5: 12pF/50V/5%/COG/C0402; C_0402_5MIL_DWS
C6: 470uF/10V/20%/Low_ESR/RM2.5/6.0x11mm; CPOL-RM2.5mm_6.3x11mm_PTH
C10: 100nF/10V/10%/X7R/C0402; C_0402_5MIL_DWS
C11: 1uF/10V/10%/X5R/C0603; C_0603_5MIL_DWS
CON1, CON2, CON3, CON4: DG306-5.0-3P; TB3-DG306-5.0_3P
D1: SMAJ58A/SMA; SMA-KA
D2, D3, D4, D5, D8, D9, D10, D11: 1N4148W(SOD-123); SOD-123_1C-2A_KA
D6: SS310/SMA; SMA-KA
D7: 1N5822/SS34/SMA; SMA-KA
ESP-PROG1: NA(WU06S); WU06S
EXT1: NA(HN1x10); HN1x10
FET1: WPM2015-3/TR; SOT23
FID1, FID2, FID3: Fiducial; Fiducial1x3
GND1: TESTPAD; TEST_PAD40x70_SQUARE
IN1, IN2, IN3, IN4: DG306-5.0-2P; TB2-DG306-5.0_2P
L1: 33uH/2.1A/DCR=0.1R/20%/DBS135(PD3316MT330); DBS135
L2: 2.2uH/1.5A/DCR=72mR/20%/3.00x3.00x1.50mm/CD32(NR3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; CD32
LED1, LED2, LED3, LED4: LED/RED/0603; LED_0603_KA
LED5, LED6, LED7, LED8: LED/GREEN/0603; LED_0603_KA
Logo_OLIMEX_TB: Logo_OLIMEX_TB
MH1, MH2, MH3, MH4: Mounting_Hole_NPTH; Mounting_Hole_Drill-3.3mm_Clerance-7mm
OPT1, OPT2, OPT3, OPT4: PC817CS_CYPC817(C-TP2); H11A817C_SMD(PC817X3NIP06)_FP
PWR1: PWRJ-2mm(YDJ-1134); PWRJ-2mm(YDJ-1136)
PWR2: NA(DG306-5.0-2P); TB2-DG306-5.0_2P
PWR_LED1: LED/RED/0603; LED_0603_KA
R1, R2: 5.1k/R0603; R_0603_5MIL_DWS
R3, R11, R15, R27, R28, R29, R30, R31: 2.2k/R0402; R_0402_5MIL_DWS
R4: 0.03R/1%/R1206; R_1206_5MIL_DWS
R5, R6, R7, R8: 3.9k/R1206; R_1206_5MIL_DWS
R9, R10, R18: NA/R0402; R_0402_5MIL_DWS
R12: 4.7R/R0402; R_0402_5MIL_DWS
R13: 5.23k/1%/R0402; R_0402_5MIL_DWS
R14, R16, R25, R26: 10k/R0402; R_0402_5MIL_DWS
R17: 30.1k/1%/R0402; R_0402_5MIL_DWS
R19: 220k/R0402; R_0402_5MIL_DWS
R20: 49.9k/1%/R0402; R_0402_5MIL_DWS
R21, R22, R23, R24: 47k/R0402; R_0402_5MIL_DWS
R32: 100R/R0402; R_0402_5MIL_DWS
R33, R34: NA(2.2k/R0402); R_0402_5MIL_DWS
REL1, REL2, REL3, REL4: RAS-0515; Relay_RAS-05-15
RST1: YTS-A016-X
Sign_Antistatic: Sign_Antistatic
Sign_CE: CE_Sign
Sign_High_Voltage: Sign_High_Voltage
Sign_High_Voltage#2, Sign_High_Voltage#3, Sign_High_Voltage#4: Sign_High_Voltage
Sign_OSHW_8x8: Sign_OSHW_8x8
Sign_PB-Free: Sign_PB-Free
Sign_RecycleBin_1: Sign_RecycleBin_1
Sign_RoHS_1: Sign_RoHS_1
T1, T2, T3, T4: LMUN2235LT1G(SOT-23); SOT23
U1: TX4138(ESOIC-8); ESOIC-8
U2: SY8089AAAC(SOT23-5); SOT-23-5
U3: ESP32-C6-WROOM-1-N4; ESP32-C6-WROOM-1-xx-UNIVERSAL_MODULE
UEXT1: P-B-V-10-LF; GBH-254-SMT-10
UEXT2: SM10B-SRSS-TB
USB-OTG1: USB-C-16P-F(A40-00119-A52-12); USB2.0_TYPE-C(A40-00119-A52-12)
USER_LED1: LED/GREEN/0603; LED_0603_KA

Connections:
+3.3V: 3.3V_E1.2, C7.1, C8.1, C9.1, C10.2, EXT1.2, L2.2, R10.1, R11.1, R14.1, R15.1, R16.1, R19.2, R21.2, R22.2, R23.2, R24.2, R25.1, R26.1, R27.1, R33.1, R34.1, U3.2, UEXT1.1, UEXT2.1
+5V: C3.1, D7.1, D8.1, D9.1, D10.1, D11.1, EXT1.1, FET1.2, R3.2, R28.2, R29.2, R30.2, R31.2, REL1.1, REL2.1, REL3.1, REL4.1, U2.1, U2.4
+5V_EXT: C5.1, C6.1, D7.2, FET1.1, L1.2, R17.1
+5V_USB: FET1.3, USB-OTG1.A4, USB-OTG1.A9, USB-OTG1.B4, USB-OTG1.B9
/CC1: R2.2, USB-OTG1.A5
/CC2: R1.2, USB-OTG1.B5
/ESP_EN: C11.1, ESP-PROG1.6, EXT1.4, R25.2, RST1.2, U3.3
/GPIO0: EXT1.5, U3.8
/GPIO1\In1: OPT1.4, R21.1, U3.9
/GPIO2\In2: OPT2.4, R22.1, U3.27
/GPIO3\In3: OPT3.4, R23.1, U3.26
/GPIO4\LP_UART_RXD: R16.2, R18.2, U3.4, UEXT1.4, UEXT2.4
/GPIO5\LP_UART_TXD: R9.2, R10.2, U3.5, UEXT1.3, UEXT2.3
/GPIO6\LP_I2C_SDA: R15.2, R34.2, U3.6, UEXT1.6, UEXT2.6
/GPIO7\LP_I2C_SCL: R11.2, R33.2, U3.7, UEXT1.5, UEXT2.5
/GPIO8\USER_LED1: EXT1.6, R26.2, U3.10, USER_LED1.1
/GPIO9\BUT1: ESP-PROG1.2, EXT1.7, R32.1, U3.15
/GPIO10\REL1: T1.1, U3.11
/GPIO11\REL2: T2.1, U3.12
/GPIO12\USB_D-: U3.13, USB-OTG1.A7, USB-OTG1.B7
/GPIO13\USB_D+: U3.14, USB-OTG1.A6, USB-OTG1.B6
/GPIO15\In4: OPT4.4, R24.1, U3.23
/GPIO16\U0TXD: ESP-PROG1.1, EXT1.8, U3.25
/GPIO17\U0RXD: ESP-PROG1.3, EXT1.9, U3.24
/GPIO18\SPI2D(MOSI)\SDIO_CMD: U3.16, UEXT1.8, UEXT2.8
/GPIO19\SPI2CLK(CLK)\SDIO_CLK: U3.17, UEXT1.9, UEXT2.9
/GPIO20\SPI2Q(MISO)\SDIO_DATA0: U3.18, UEXT1.7, UEXT2.7
/GPIO21\SPI2CS0(CS#)\SDIO_CD: R14.2, U3.19, UEXT1.10, UEXT2.10
/GPIO22\REL3: T3.1, U3.20
/GPIO23\REL4: T4.1, U3.21
/ILIM: R4.1, U1.2, U1.9
/VIN: C1.1, C2.1, D1.1, PWR1.+, PWR2.1, R4.2, U1.3
GND: BUT1.2, C1.2, C2.2, C3.2, C6.2, C7.2, C8.2, C9.2, C10.1, C11.2, D1.2, D6.2, ESP-PROG1.4, EXT1.3, EXT1.10, GND1.1, OPT1.3, OPT2.3, OPT3.3, OPT4.3, PWR1.-, PWR2.2, PWR_LED1.1, R1.1, R2.1, R9.1, R13.2, R18.1, R20.2, RST1.1, T1.2, T2.2, T3.2, T4.2, U1.4, U2.2, U3.1, U3.28, U3.29, UEXT1.2, UEXT2.2, USB-OTG1.0, USB-OTG1.A1, USB-OTG1.A12, USB-OTG1.B1, USB-OTG1.B12
unnamed: 3.3V_E1.1, ESP-PROG1.5
unnamed: BUT1.1, R32.2
unnamed: C4.1, D6.1, L1.1, U1.1
unnamed: C4.2, R12.2
unnamed: C5.2, R13.1, R17.2, U1.5
unnamed: CON1.1, REL1.NO0
unnamed: CON1.2, REL1.COM0
unnamed: CON1.3, REL1.NC0
unnamed: CON2.1, REL2.NO0
unnamed: CON2.2, REL2.COM0
unnamed: CON2.3, REL2.NC0
unnamed: CON3.1, REL3.NO0
unnamed: CON3.2, REL3.COM0
unnamed: CON3.3, REL3.NC0
unnamed: CON4.1, REL4.NO0
unnamed: CON4.2, REL4.COM0
unnamed: CON4.3, REL4.NC0
unnamed: D2.1, LED1.2, R5.2
unnamed: D2.2, IN1.2, OPT1.2
unnamed: D3.1, LED2.2, R6.2
unnamed: D3.2, IN2.2, OPT2.2
unnamed: D4.1, LED3.2, R7.2
unnamed: D4.2, IN3.2, OPT3.2
unnamed: D5.1, LED4.2, R8.2
unnamed: D5.2, IN4.2, OPT4.2
unnamed: D8.2, LED5.1, REL1.2, T1.3
unnamed: D9.2, LED6.1, REL2.2, T2.3
unnamed: D10.2, LED7.1, REL3.2, T3.3
unnamed: D11.2, LED8.1, REL4.2, T4.3
unnamed: IN1.1, R5.1
unnamed: IN2.1, R6.1
unnamed: IN3.1, R7.1
unnamed: IN4.1, R8.1
unnamed: L2.1, U2.3
unnamed: LED1.1, OPT1.1
unnamed: LED2.1, OPT2.1
unnamed: LED3.1, OPT3.1
unnamed: LED4.1, OPT4.1
unnamed: LED5.2, R28.1
unnamed: LED6.2, R29.1
unnamed: LED7.2, R30.1
unnamed: LED8.2, R31.1
unnamed: PWR_LED1.2, R3.1
unnamed: R12.1, U1.8
unnamed: R19.1, R20.1, U2.5
unnamed: R27.2, USER_LED1.2

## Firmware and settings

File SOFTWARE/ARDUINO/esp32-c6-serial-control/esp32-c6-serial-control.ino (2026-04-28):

// ======================================================
// ESP32-C6 EVB - Serial Control Console
// Open Serial Monitor and type help
// ======================================================

#define RELAY1 10
#define RELAY2 11
#define RELAY3 22
#define RELAY4 23

#define USER_LED 8
#define USER_BUTTON 9

#define OPTO1 1
#define OPTO2 2
#define OPTO3 3
#define OPTO4 15

#define RELAY_ON  HIGH
#define RELAY_OFF LOW

int relayPins[4] = {RELAY1, RELAY2, RELAY3, RELAY4};
int optoPins[4]  = {OPTO1, OPTO2, OPTO3, OPTO4};

bool demoMode = false;
int demoIndex = 0;
unsigned long lastDemoTime = 0;

String inputBuffer = "";

// ======================================================
// SETUP
// ======================================================
void setup() {
  Serial.begin(115200);
  delay(2000);

  Serial.println("\nESP32-C6 EVB Serial Console");
  Serial.println("Type 'help'");

  for (int i = 0; i < 4; i++) {
    pinMode(relayPins[i], OUTPUT);
    digitalWrite(relayPins[i], RELAY_OFF);
  }

  pinMode(USER_LED, OUTPUT);
  digitalWrite(USER_LED, HIGH); // OFF (active LOW)

  pinMode(USER_BUTTON, INPUT_PULLUP);

  for (int i = 0; i < 4; i++) {
    pinMode(optoPins[i], INPUT);
  }
}

// ======================================================
// HELP MENU
// ======================================================
void printHelp() {
  Serial.println("\nCommands:");
  Serial.println(" help");
  Serial.println(" relay on <1-4>");
  Serial.println(" relay off <1-4>");
  Serial.println(" relay toggle <1-4>");
  Serial.println(" relay status");
  Serial.println(" opto status");
  Serial.println(" led on/off/toggle");
  Serial.println(" button");
  Serial.println(" demo start/stop");
  Serial.println(" status");
}

// ======================================================
// STATUS FUNCTIONS
// ======================================================
bool relayState(int i) {
  return digitalRead(relayPins[i]) == RELAY_ON;
}

void printRelayStatus() {
  Serial.println("Relays:");
  for (int i = 0; i < 4; i++) {
    Serial.printf("  R%d: %s\n", i + 1, relayState(i) ? "ON" : "OFF");
  }
}

void printOptoStatus() {
  Serial.println("Opto inputs:");
  for (int i = 0; i < 4; i++) {
    bool active = digitalRead(optoPins[i]) == LOW;
    Serial.printf("  IN%d: %s\n", i + 1, active ? "ACTIVE" : "IDLE");
  }
}

void printButton() {
  bool pressed = digitalRead(USER_BUTTON) == LOW;
  Serial.printf("Button: %s\n", pressed ? "PRESSED" : "RELEASED");
}

void printStatus() {
  printRelayStatus();
  printOptoStatus();
  printButton();
}

// ======================================================
// RELAY CONTROL
// ======================================================
void setRelay(int idx, bool state) {
  if (idx < 0 || idx > 3) return;
  digitalWrite(relayPins[idx], state ? RELAY_ON : RELAY_OFF);
}

// ======================================================
// COMMAND PARSER
// ======================================================
void processCommand(String cmd) {
  cmd.trim();

  if (cmd == "help") {
    printHelp();
  }

  else if (cmd.startsWith("relay")) {
    int num = cmd.substring(cmd.length() - 1).toInt() - 1;

    if (cmd.indexOf("on") > 0) setRelay(num, true);
    else if (cmd.indexOf("off") > 0) setRelay(num, false);
    else if (cmd.indexOf("toggle") > 0)
      setRelay(num, !relayState(num));
    else if (cmd.indexOf("status") > 0)
      printRelayStatus();
  }

  else if (cmd == "opto status") {
    printOptoStatus();
  }

  else if (cmd == "led on") {
    digitalWrite(USER_LED, LOW);
  }
  else if (cmd == "led off") {
    digitalWrite(USER_LED, HIGH);
  }
  else if (cmd == "led toggle") {
    digitalWrite(USER_LED, !digitalRead(USER_LED));
  }

  else if (cmd == "button") {
    printButton();
  }

  else if (cmd == "demo start") {
    demoMode = true;
    Serial.println("Demo started");
  }

  else if (cmd == "demo stop") {
    demoMode = false;
    Serial.println("Demo stopped");
  }

  else if (cmd == "status") {
    printStatus();
  }

  else {
    Serial.println("Unknown command");
  }
}

// ======================================================
// SERIAL INPUT HANDLER
// ======================================================
void handleSerial() {
  while (Serial.available()) {
    char c = Serial.read();

    if (c == '\n') {
      processCommand(inputBuffer);
      inputBuffer = "";
    } else {
      inputBuffer += c;
    }
  }
}

// ======================================================
// DEMO MODE
// ======================================================
void runDemo() {
  if (!demoMode) return;

  if (millis() - lastDemoTime > 2000) {
    lastDemoTime = millis();

    for (int i = 0; i < 4; i++)
      digitalWrite(relayPins[i], RELAY_OFF);

    digitalWrite(relayPins[demoIndex], RELAY_ON);

    digitalWrite(USER_LED, demoIndex % 2 ? LOW : HIGH);

    demoIndex = (demoIndex + 1) % 4;
  }
}

// ======================================================
// LOOP
// ======================================================
void loop() {
  handleSerial();
  runDemo();
}

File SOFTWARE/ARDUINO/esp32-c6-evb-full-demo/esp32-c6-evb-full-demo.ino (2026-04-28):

// ======================================================
// ESP32-C6-EVB (Olimex) - full demo
//
// Features:
// - 4 relays rotate every 2 seconds
// - User LED blinks every 2 seconds (active LOW)
// - Button toggles relay rotation ON/OFF
// - 4 optocoupler inputs monitored (event-based logging)
//
// Hardware specifics:
// - Native USB used for Serial
// - Relays: ACTIVE HIGH
// - LED: ACTIVE LOW
// - Button: ACTIVE LOW (internal pull-up)
// - Optocouplers: ACTIVE LOW (47k pull-up to 3.3V),
// provide between 5V DC and 30V DC and be careful
// with polarity!!!
//
// After downloading the demo, open the serial monitor
// Ensure that "USB CDC On Boot" is Enabled
// Refer to "arduino-settings.jpg" for tested settings
// ======================================================


// ===== Relay pin definitions =====
#define RELAY1 10
#define RELAY2 11
#define RELAY3 22
#define RELAY4 23

// ===== User interface =====
#define USER_LED 8
#define USER_BUTTON 9

// ===== Optocoupler inputs =====
#define OPTO1 1
#define OPTO2 2
#define OPTO3 3
#define OPTO4 15


// ===== Timing (milliseconds) =====
const unsigned long RELAY_INTERVAL = 2000;
const unsigned long LED_INTERVAL   = 2000;


// ===== Relay logic =====
// Board is ACTIVE HIGH:
// HIGH = relay ON
// LOW  = relay OFF
#define RELAY_ON  HIGH
#define RELAY_OFF LOW


// ===== State variables =====
unsigned long lastRelayTime = 0;
unsigned long lastLedTime   = 0;

int currentRelay = 0;        // internal index (0–3)
bool relaysRunning = true;

bool ledState = false;
bool lastButtonState = HIGH;


// ===== Pin arrays for iteration =====
int relayPins[4] = {RELAY1, RELAY2, RELAY3, RELAY4};
int optoPins[4]  = {OPTO1, OPTO2, OPTO3, OPTO4};


// ===== Optocoupler state tracking =====
// Used to detect changes (edge detection)
bool lastOptoState[4] = {HIGH, HIGH, HIGH, HIGH};


// ======================================================
// SETUP
// ======================================================
void setup() {
  // Start native USB serial
  Serial.begin(115200);

  // Delay to allow terminal to connect (important for USB CDC)
  delay(2000);

  Serial.println("\nESP32-C6 EVB Full Demo Start");

  // ----- Initialize relays (all OFF) -----
  for (int i = 0; i < 4; i++) {
    pinMode(relayPins[i], OUTPUT);
    digitalWrite(relayPins[i], RELAY_OFF);
  }

  // ----- Initialize user LED (OFF) -----
  pinMode(USER_LED, OUTPUT);
  digitalWrite(USER_LED, HIGH); // HIGH = OFF (active LOW LED)

  // ----- Initialize button -----
  // Internal pull-up → pressed = LOW
  pinMode(USER_BUTTON, INPUT_PULLUP);

  // ----- Initialize optocoupler inputs -----
  // External pull-ups already present on board (47k)
  for (int i = 0; i < 4; i++) {
    pinMode(optoPins[i], INPUT);
  }
}


// ======================================================
// HELPER: Check if relay is logically ON
// ======================================================
bool isRelayOn(int i) {
  return digitalRead(relayPins[i]) == RELAY_ON;
}


// ======================================================
// PRINT RELAY STATUS
// ======================================================
void printRelayStatus() {
  Serial.println("=== RELAY STATUS ===");

  for (int i = 0; i < 4; i++) {
    Serial.print("Relay ");
    Serial.print(i + 1);  // numbering
    Serial.print(": ");
    Serial.println(isRelayOn(i) ? "ON" : "OFF");
  }

  Serial.println("====================");
}


// ======================================================
// PRINT OPTOCOUPLER STATUS
// ======================================================
void printOptoStatus() {
  Serial.println("=== OPTO INPUT STATUS ===");

  for (int i = 0; i < 4; i++) {
    Serial.print("IN");
    Serial.print(i + 1);
    Serial.print(": ");

    // ACTIVE LOW → LOW means input is active
    bool active = (digitalRead(optoPins[i]) == LOW);
    Serial.println(active ? "ACTIVE" : "IDLE");
  }

  Serial.println("==========================");
}


// ======================================================
// MAIN LOOP
// ======================================================
void loop() {
  unsigned long now = millis();


  // ==================================================
  // BUTTON HANDLING (edge detection + debounce)
  // ==================================================
  bool currentButtonState = digitalRead(USER_BUTTON);

  // Detect button press (HIGH → LOW transition)
  if (lastButtonState == HIGH && currentButtonState == LOW) {
    delay(30); // simple debounce

    if (digitalRead(USER_BUTTON) == LOW) {
      relaysRunning = !relaysRunning;

      Serial.println("\n[EVENT] Button pressed");
      Serial.print("Relay rotation: ");
      Serial.println(relaysRunning ? "RUNNING" : "STOPPED");

      printRelayStatus();
      printOptoStatus();
    }
  }

  lastButtonState = currentButtonState;


  // ==================================================
  // RELAY SEQUENCER
  // ==================================================
  if (relaysRunning && (now - lastRelayTime >= RELAY_INTERVAL)) {
    lastRelayTime = now;

    // Turn all relays OFF
    for (int i = 0; i < 4; i++) {
      digitalWrite(relayPins[i], RELAY_OFF);
    }

    // Turn current relay ON
    digitalWrite(relayPins[currentRelay], RELAY_ON);

    Serial.print("Active relay -> ");
    Serial.println(currentRelay + 1);

    // Move to next relay (circular)
    currentRelay = (currentRelay + 1) % 4;
  }


  // ==================================================
  // LED BLINK (independent task)
  // ==================================================
  if (now - lastLedTime >= LED_INTERVAL) {
    lastLedTime = now;

    ledState = !ledState;

    // ACTIVE LOW LED:
    // LOW = ON, HIGH = OFF
    digitalWrite(USER_LED, ledState ? LOW : HIGH);

    Serial.print("LED: ");
    Serial.println(ledState ? "ON" : "OFF");
  }


  // ==================================================
  // OPTOCOUPLER MONITORING (change detection)
  // ==================================================
  for (int i = 0; i < 4; i++) {
    bool currentState = digitalRead(optoPins[i]);

    // Detect change
    if (currentState != lastOptoState[i]) {
      lastOptoState[i] = currentState;

      Serial.print("[OPTO EVENT] IN");
      Serial.print(i + 1);
      Serial.print(" -> ");

      // ACTIVE LOW logic
      Serial.println(currentState == LOW ? "ACTIVE" : "IDLE");
    }
  }
}

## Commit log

2023-07-04 Update
    Schematics
    [Cap_PTH_10x16x5_0mm.step, Cap_PTH_6_3x11x2_5mm.step, DIP4_opto_iso.step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]
2023-07-04 Update
    Schematic export and demo
2023-10-11 Adding STL files for 3d printed case
    [esp_evb_bottom.stl, esp_evb_top.stl]
2023-10-11 updating names on STL files to match board name
    [esp_c6_evb_bottom.stl, esp_c6_evb_top.stl]
2024-07-01 Update
    Dimensions
    [ESP32-C6-EVB_DIMM_Rev_A.kicad_pcb]
2026-04-28 New demo
    Arduino demo for relays, optocoupler inputs, button, user LED.
2026-04-28 Added new Arduino demo
    Board control via serial via commands

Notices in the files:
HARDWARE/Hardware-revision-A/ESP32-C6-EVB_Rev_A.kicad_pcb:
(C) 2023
